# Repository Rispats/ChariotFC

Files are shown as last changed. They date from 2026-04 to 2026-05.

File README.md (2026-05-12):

# ChariotFC

> Custom Flight Controller + PDB for General Free Style and Auotpilot applications

## Specs
- **FMU:** AT32F435RMT7 (288Mhz, Hardware FPU)
- **Power Distrubution Board:** 2S-6S LiPo 
- **From Factor:** 30.5mm X 30.5mm Dual stack (FC + PDB)
- **Target Firmware:** PX4, Betaflight

STATUS: PCB Design in progress

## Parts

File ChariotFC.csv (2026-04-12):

Reference | Qty | Value | DNP | Exclude from BOM | Exclude from Board | Footprint | Datasheet
BUZZER1 | 1 | MLT-7525 |  |  | Excluded from board | easyeda2kicad:BUZ-SMD_4P-L7.5-W7.5-P7.59-TL | https://lcsc.com/product-detail/Buzzers_MLT-7525_C95299.html
C1,C8 | 2 | 1uF |  |  |  | easyeda2kicad:C0402 | https://lcsc.com/product-detail/Multilayer-Ceramic-Capacitors-MLCC-SMD-SMT_SAMSUNG_CL05A105KA5NQNC_1uF-105-10-25V_C52923.html,https://lcsc.com/product-detail/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
C2,C3,C4,C9,C11,C12,C13,C14,C40 | 9 | 100nF |  |  |  | easyeda2kicad:C0402 | https://lcsc.com/product-detail/Multilayer-Ceramic-Capacitors-MLCC-SMD-SMT_SAMSUNG_CL05A104KA5NNNC_100nF-104-10-25V_C100072.html,https://lcsc.com/product-deta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
C5,C20,C35 | 3 | 100nF |  |  |  | PCM_JLCPCB:C_0402 | https://www.lcsc.com/datasheet/lcsc_datasheet_2304140030_Samsung-Electro-Mechanics-CL05B104KB54PNC_C307331.pdf,https://www.lcsc.com/datasheet/lcsc_datasheet_2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
C6,C7 | 2 | 33pF |  |  |  | easyeda2kicad:C0402 | https://lcsc.com/product-detail/Multilayer-Ceramic-Capacitors-MLCC-SMD-SMT_33pF-330-5-50V_C1562.html
C10 | 1 | 10nF |  |  |  | easyeda2kicad:C0402 | https://lcsc.com/product-detail/Multilayer-Ceramic-Capacitors-MLCC-SMD-SMT_muRata_GRM155R71H103KA88D_10nF-103-10-50V_C77019.html
C15 | 1 | 4.7uF |  |  |  | easyeda2kicad:C0805 | https://lcsc.com/product-detail/Multilayer-Ceramic-Capacitors-MLCC-SMD-SMT_SAMSUNG_CL21A475KAQNNNE_4-7uF-475-10-25V_C1779.html
C16,C17,C18,C19 | 4 | 1uF |  |  |  | PCM_JLCPCB:C_0402 | https://www.lcsc.com/datasheet/lcsc_datasheet_2304140030_Samsung-Electro-Mechanics-CL05A105KA5NQNC_C52923.pdf
C21 | 1 | 10uF |  |  |  | easyeda2kicad:C1206
C22,C23,C25,C26,C27,C29,C30,C31 | 8 | 100nF |  |  | Excluded from board | PCM_JLCPCB:C_0402 | https://www.lcsc.com/datasheet/lcsc_datasheet_2304140030_Samsung-Electro-Mechanics-CL05B104KO5NNNC_C1525.pdf
C24 | 1 | 10uF |  |  | Excluded from board | PCM_JLCPCB:C_0603 | https://www.lcsc.com/datasheet/lcsc_datasheet_2304140030_Samsung-Electro-Mechanics-CL10A106KP8NNNC_C19702.pdf
C28 | 1 | 1uF |  |  | Excluded from board | PCM_JLCPCB:C_0402 | https://www.lcsc.com/datasheet/lcsc_datasheet_2304140030_Samsung-Electro-Mechanics-CL05A105KA5NQNC_C52923.pdf
C32,C33 | 2 | 10uF |  |  |  | PCM_JLCPCB:C_0805 | https://www.lcsc.com/datasheet/lcsc_datasheet_2411041759_Murata-Electronics-GRM21BR61H106KE43L_C440198.pdf
C34 | 1 | 10nF |  |  |  | PCM_JLCPCB:C_0402 | https://www.lcsc.com/datasheet/lcsc_datasheet_2304140030_Samsung-Electro-Mechanics-CL05B103KB5NNNC_C15195.pdf
C36 | 1 | 33nF |  |  |  | PCM_JLCPCB:C_0603 | https://www.lcsc.com/datasheet/lcsc_datasheet_2304140030_Samsung-Electro-Mechanics-CL10B333KB8NNNC_C21117.pdf
C37 | 1 | 100nF 25v |  |  |  | easyeda2kicad:C0402 | https://lcsc.com/product-detail/Multilayer-Ceramic-Capacitors-MLCC-SMD-SMT_SAMSUNG_CL05A104KA5NNNC_100nF-104-10-25V_C100072.html
C38,C39 | 2 | 22uF |  |  |  | easyeda2kicad:C1206 | https://lcsc.com/product-detail/Multilayer-Ceramic-Capacitors-MLCC-SMD-SMT_muRata_GRM31CR71A226KE15L_22uF-226-10-10V_C91604.html
D1,D2 | 2 | PMEG4020ER,115 |  |  |  | easyeda2kicad:SOD-123_L2.8-W1.8-LS3.7-RD | https://lcsc.com/product-detail/Others_Nexperia_PMEG4020ER-115_Nexperia-PMEG4020ER-115_C255588.html
D3 | 1 | 1N4148W_C81598 |  |  | Excluded from board | easyeda2kicad:SOD-123F_L2.7-W1.6-LS3.8-RD | https://lcsc.com/product-detail/Switching-Diode_1N4148W_C81598.html
D4 | 1 | MM3Z3V3T1G |  |  |  | easyeda2kicad:SOD-323_L1.8-W1.3-LS2.5-RD | https://lcsc.com/product-detail/Zener-Diodes_ON_MM3Z3V3T1G_MM3Z3V3T1G_C75073.html
L1 | 1 | BLM15AG601SN1D |  |  |  | easyeda2kicad:L0402 | https://lcsc.com/product-detail/Ferrite-Beads-And-Chips_muRata_BLM15AG601SN1D_600R-at100MHz_C76884.html
L2 | 1 | 6.8uH |  |  |  | easyeda2kicad:IND-SMD_L7.1-W6.6
LED1 | 1 | 3v3_PWR |  |  |  | easyeda2kicad:LED0805-R-RD | https://lcsc.com/product-detail/Light-Emitting-Diodes-LED_Green-0805-Highlighted_C2297.html
LED2 | 1 | 3v3_SENSORS_PWR |  |  |  | easyeda2kicad:LED0805-R-RD | https://lcsc.com/product-detail/Light-Emitting-Diodes-LED_Green-0805-Highlighted_C2297.html
LED3 | 1 | KT-0603R |  |  | Excluded from board | easyeda2kicad:LED0603-RD | https://lcsc.com/product-detail/Light-Emitting-Diodes-LED_Red-LED-0603_C2286.html
LED4 | 1 | XL-0603QYGC |  |  | Excluded from board | easyeda2kicad:LED0603-RD | https://lcsc.com/product-detail/Light-Emitting-Diodes-LED_Yellow-green-0603_C2289.html
LED5 | 1 | SYS_PWR_ON |  |  |  | easyeda2kicad:LED0603-RD | https://lcsc.com/product-detail/Light-Emitting-Diodes-LED_Red-LED-0603_C2286.html
Q1 | 1 | 2N7002 |  |  | Excluded from board | easyeda2kicad:SOT-23-3_L2.9-W1.3-P1.90-LS2.4-BR | https://lcsc.com/product-detail/MOSFET_2N7002-7002_C8545.html
R1,R3,R4,R5 | 4 | 10k |  |  |  | easyeda2kicad:R0402 | https://lcsc.com/product-detail/Chip-Resistor-Surface-Mount_10KR-1002-1_C60490.html
R2 | 1 | 10kΩ |  |  |  | PCM_JLCPCB:R_0402x4 | https://www.lcsc.com/datasheet/lcsc_datasheet_2409272301_UNI-ROYAL-Uniroyal-Elec-4D02WGJ0103TCE_C25725.pdf
R6,R7 | 2 | 5.1kΩ |  |  |  | PCM_JLCPCB:R_0402 | https://www.lcsc.com/datasheet/lcsc_datasheet_2206010045_UNI-ROYAL-Uniroyal-Elec-0402WGF5101TCE_C25905.pdf
R8,R9 | 2 | 100 |  |  |  | easyeda2kicad:R0402 | https://lcsc.com/product-detail/Chip-Resistor-Surface-Mount-UniOhm_100R-1000-1_C25076.html
R10,R11 | 2 | 22Ω |  |  |  | PCM_JLCPCB:R_0402 | https://www.lcsc.com/datasheet/lcsc_datasheet_2205311900_UNI-ROYAL-Uniroyal-Elec-0402WGF220JTCE_C25092.pdf
R12 | 1 | 100 |  |  | Excluded from board | easyeda2kicad:R0402 | https://lcsc.com/product-detail/Chip-Resistor-Surface-Mount-UniOhm_100R-1000-1_C25076.html
R13,R19 | 2 | 10kΩ |  |  | Excluded from board | PCM_JLCPCB:R_0402 | https://www.lcsc.com/datasheet/lcsc_datasheet_2411221126_UNI-ROYAL-Uniroyal-Elec-0402WGF1002TCE_C25744.pdf
R14 | 1 | 100kΩ |  |  | Excluded from board | PCM_JLCPCB:R_0402 | https://www.lcsc.com/datasheet/lcsc_datasheet_2206010100_UNI-ROYAL-Uniroyal-Elec-0402WGF1003TCE_C25741.pdf
R15,R16,R17,R18 | 4 | 33Ω |  |  | Excluded from board | PCM_JLCPCB:R_0402 | https://www.lcsc.com/datasheet/lcsc_datasheet_2205311900_UNI-ROYAL-Uniroyal-Elec-0402WGF330JTCE_C25105.pdf
R20 | 1 | 2m |  |  |  | easyeda2kicad:RES-SMD_L6.4-W3.2-1
R21 | 1 | 100Ω |  |  |  | PCM_JLCPCB:R_0402 | https://www.lcsc.com/datasheet/lcsc_datasheet_2205311900_UNI-ROYAL-Uniroyal-Elec-0402WGF1000TCE_C25076.pdf
R22 | 1 | 75kΩ |  |  |  | PCM_JLCPCB:R_0402 | https://www.lcsc.com/datasheet/lcsc_datasheet_2206010045_UNI-ROYAL-Uniroyal-Elec-0402WGF7502TCE_C25798.pdf
R23 | 1 | 10kΩ |  |  |  | PCM_JLCPCB:R_0402 | https://www.lcsc.com/datasheet/lcsc_datasheet_2411221126_UNI-ROYAL-Uniroyal-Elec-0402WGF1002TCE_C25744.pdf
R24 | 1 | 10.2k |  |  |  | easyeda2kicad:R0805
R25 | 1 | 220Ω |  |  |  | PCM_JLCPCB:R_0603 | https://www.lcsc.com/datasheet/lcsc_datasheet_2206010130_UNI-ROYAL-Uniroyal-Elec-0603WAF2200T5E_C22962.pdf
SIM1 | 1 | SD CARD |  |  |  | easyeda2kicad:SIM-SMD_8P-1040310811
SW1,SW2 | 2 | 1TS009A-1800-5000 |  |  |  | easyeda2kicad:KEY-SMD_L6.0-W6.0-LS6.6 | https://lcsc.com/product-detail/Others_HYP-1TS009A-1800-5000_C319409.html
TP1,TP2,TP3,TP4,TP5,TP6,TP7,TP8,TP9,TP10,TP11,TP12,TP13,TP14,TP15,TP16,TP17,TP18 | 18 | TestPoint |  |  | Excluded from board |  | ~
TP19,TP21,TP23,TP25,TP27 | 5 | BATT+ |  |  |  |  | ~
TP20,TP22,TP24,TP26,TP28 | 5 | BATT- |  |  |  |  | ~
TP29 | 1 | 5V_test |  |  |  |  | ~
TP30 | 1 | GND |  |  |  |  | ~
U1 | 1 | AT32F435RMT7 |  |  |  | easyeda2kicad:LQFP-64_L10.0-W10.0-P0.50-LS12.0-BL
U2 | 1 | FM25V20A-DGTR_C2952834 |  |  |  | easyeda2kicad:DFN-8_L6.0-W5.0-P1.27-BL-EP
U3 | 1 | NCP167BMX330TBG |  |  |  | easyeda2kicad:XDFN-4_L1.0-W1.0-P0.65-BL-EP
U4 | 1 | TLV75733PDRVR |  |  |  | easyeda2kicad:TDFN-6_L2.0-W2.0-P0.65-TL-EP
U5,U14 | 2 | B6B-XH-A(LF)(SN) |  |  |  | easyeda2kicad:CONN-TH_6P-P2.50_B6B-XH-A-LF-SN | https://lcsc.com/product-detail/XH-Connectors_JST-Sales-America_B6B-XH-A-LF-SN_JST-Sales-America-B6B-XH-A-LF-SN_C144397.html
U6 | 1 | USBLC6-2SC6Y_C2969755 |  |  |  | easyeda2kicad:SOT-23-6_L2.9-W1.7-P0.95-LS2.8-BL
U7 | 1 | MMC5983MA |  |  | Excluded from board | easyeda2kicad:LGA-16_L3.0-W3.0-P0.50-BL_SQ | https://lcsc.com/product-detail/Magnetic-Sensors_MEMSIC-MMC5983MA_C404329.html
U8 | 1 | ICM-45686 |  |  | Excluded from board | easyeda2kicad:LGA-14_L3.0-W2.5-P0.50-TL
U9 | 1 | ICP-20100 |  |  | Excluded from board | easyeda2kicad:LGA-10_L2.0-W2.0-P0.50-TL_ICP-20100
U10 | 1 | SAM-M10Q-00B |  |  | Excluded from board | easyeda2kicad:LCC-20_L15.5-W15.5-P1.90_SAM-M10Q-00B
U11 | 1 | INA240A1QDRQ1 |  |  |  | easyeda2kicad:SOIC-8_L4.9-W3.9-P1.27-LS6.0-BL-2
U12 | 1 | TPS62933DRLR |  |  |  | easyeda2kicad:SOT-583-8_L2.1-W1.2-P0.50-LS1.6-BR
U13 | 1 | 53.6k |  |  |  | easyeda2kicad:R0603
USBC1 | 1 | TYPE-C-31-M-12 |  |  |  | easyeda2kicad:USB-C_SMD-TYPE-C-31-M-12_1 | https://lcsc.com/product-detail/USB-Type-C_Korean-Hroparts-Elec-TYPE-C-31-M-12_C165948.html
X1 | 1 | ABM3-8.000MHZ-D2Y-T |  |  |  | easyeda2kicad:OSC-SMD_L5.0-W3.2 | https://lcsc.com/product-detail/SMD-Crystals_ABRACON_ABM3-8-000MHZ-D2Y-T_8MHZ-20ppm-400C-850C_C144380.html

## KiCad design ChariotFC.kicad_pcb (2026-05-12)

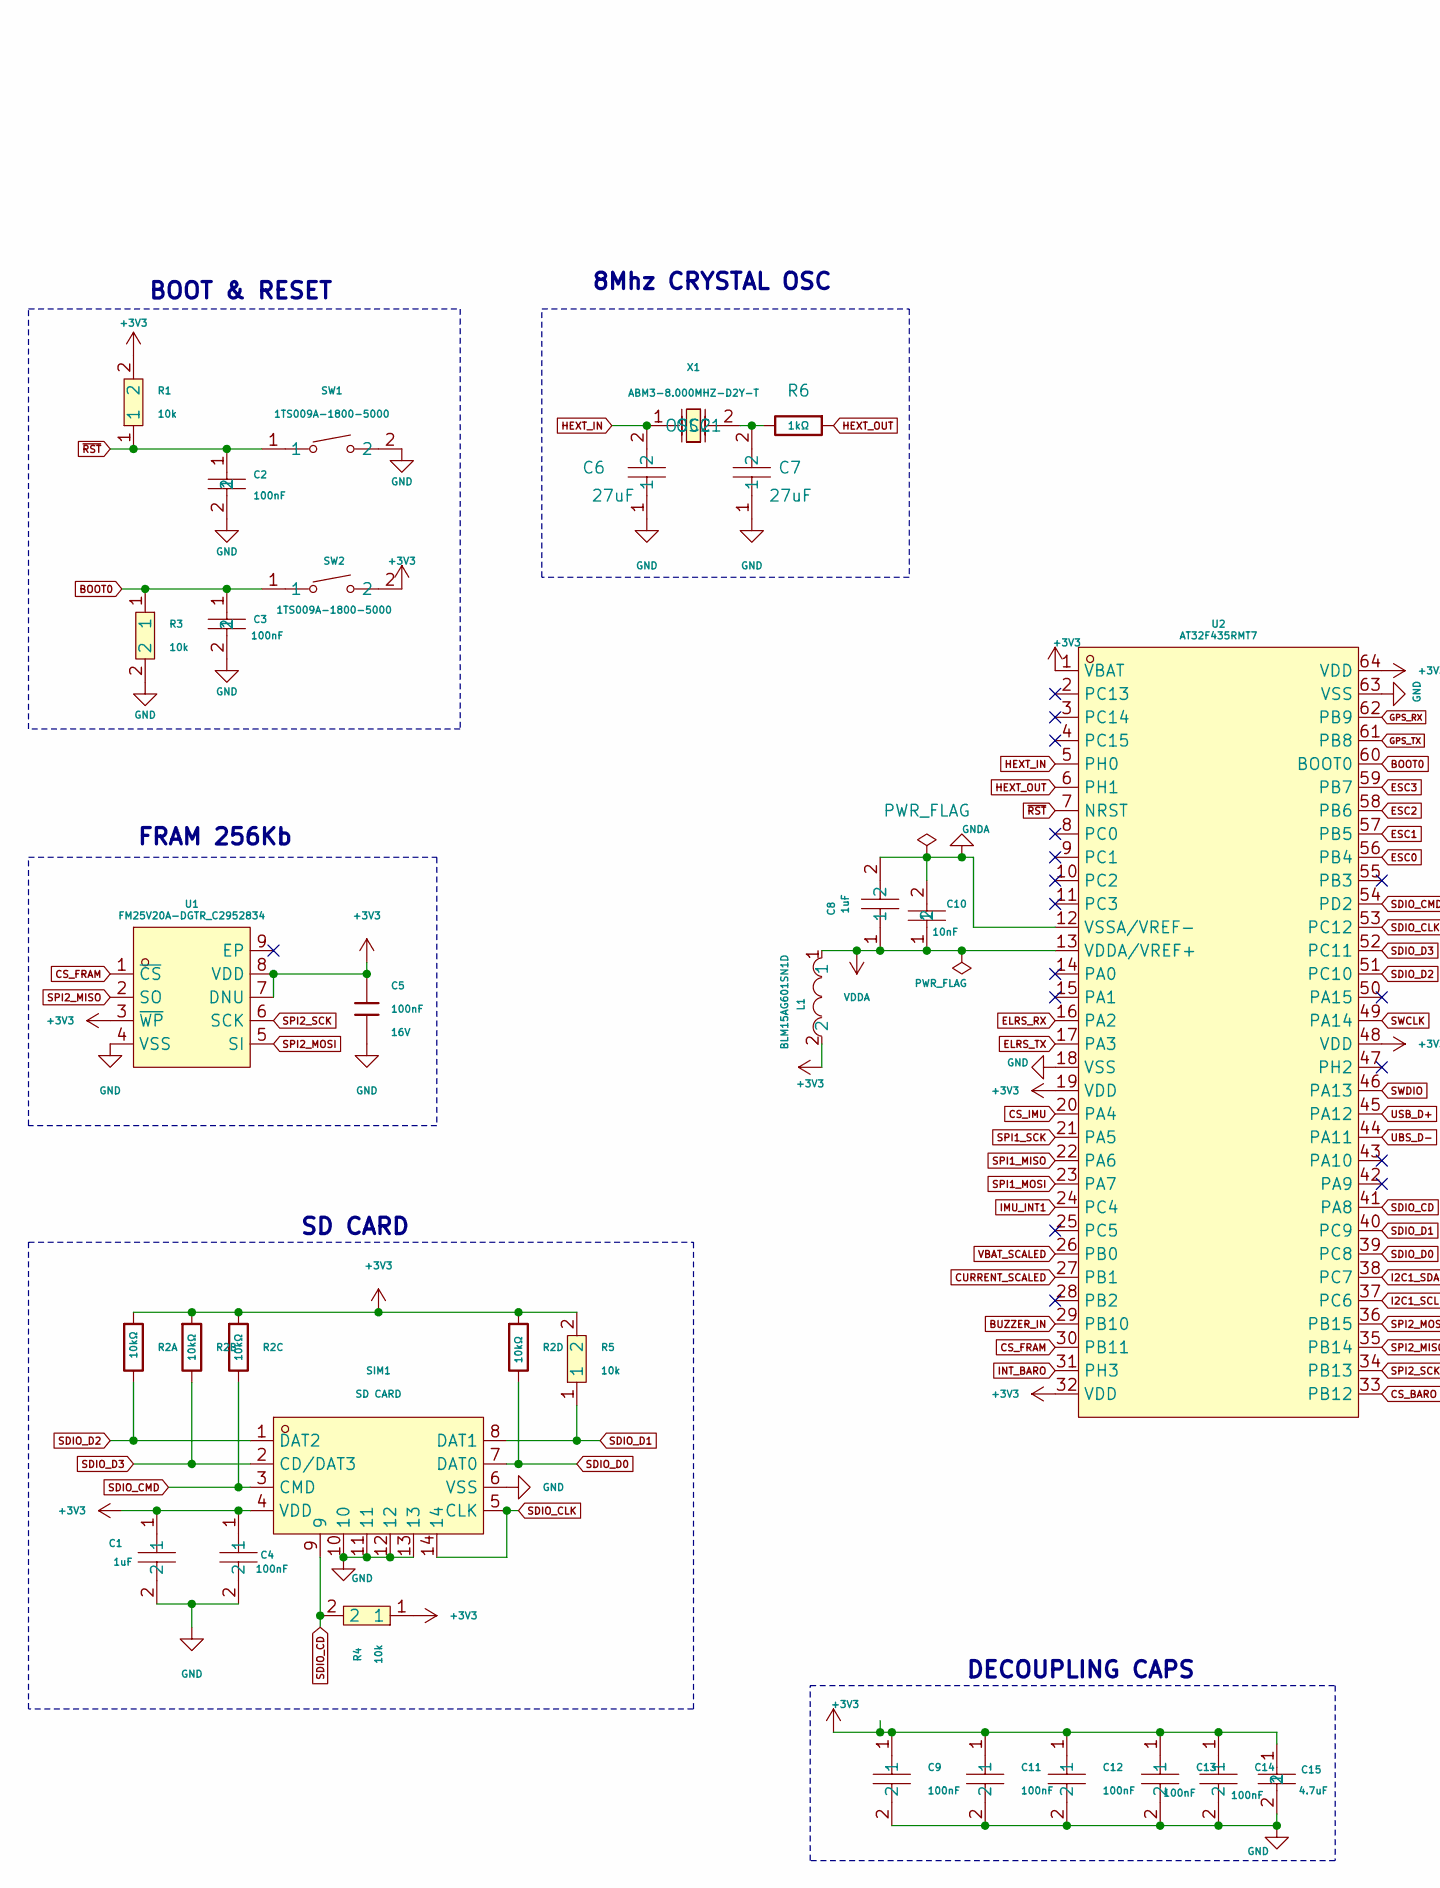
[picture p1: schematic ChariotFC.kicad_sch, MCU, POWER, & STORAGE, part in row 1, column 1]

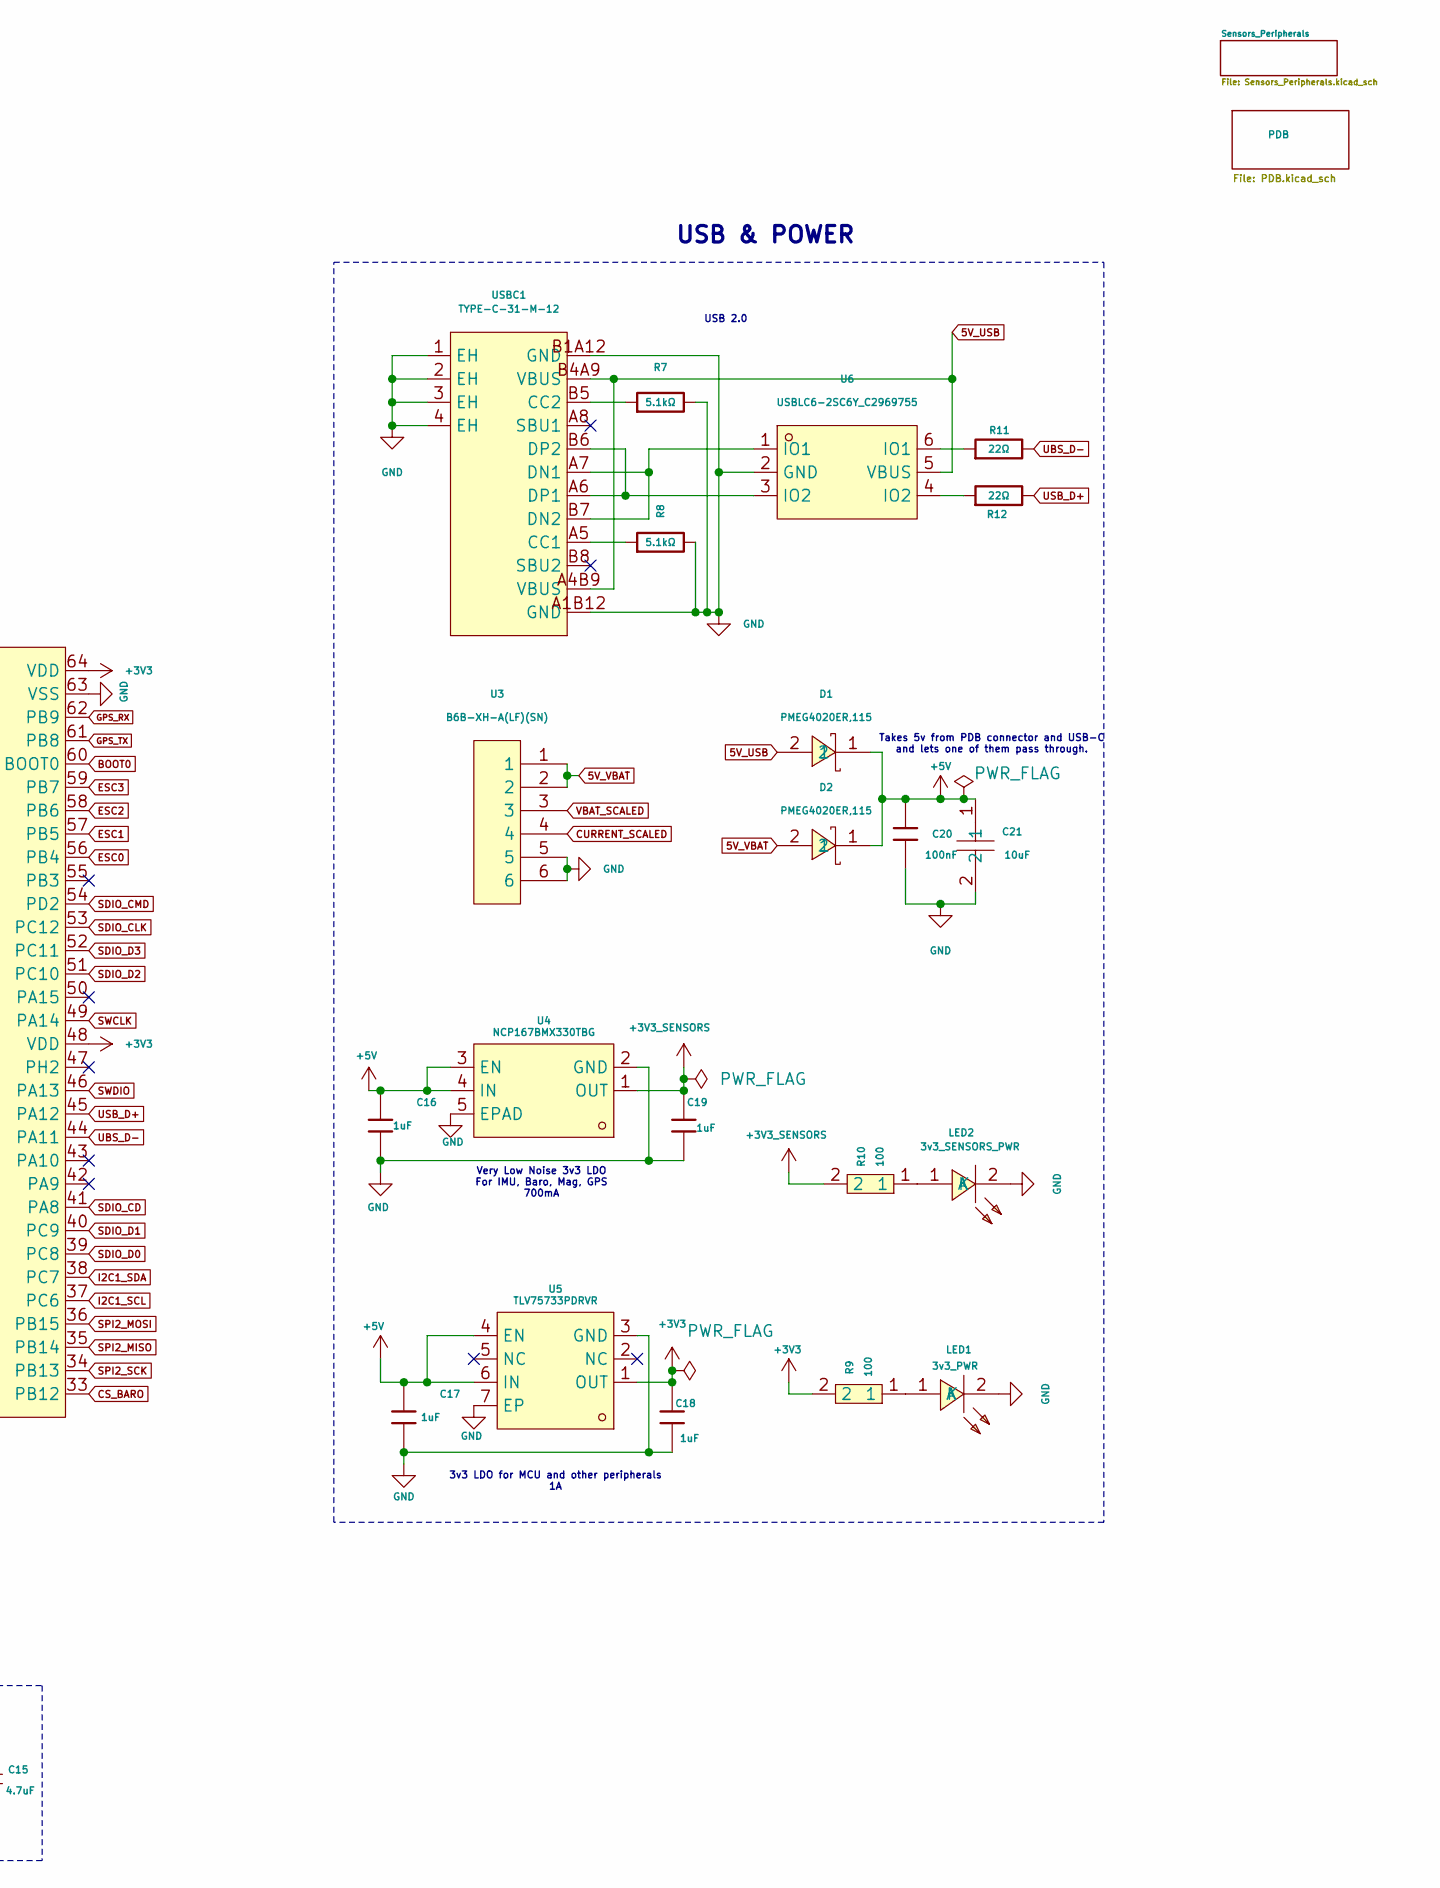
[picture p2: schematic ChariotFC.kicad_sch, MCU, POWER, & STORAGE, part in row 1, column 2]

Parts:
C1: 1uF; C0402; LCSC Part C52923
C2, C3: 100nF; C0402; LCSC Part C77019
C4, C9, C11, C12, C13, C14: 100nF; C0402; LCSC Part C1525
C5, C20: 100nF; C0402; Voltage Rated 16V; Tolerance ±10%; Part CL05B104KO5NNNC; LCSC C1525
C6, C7: 27uF; C0402; LCSC Part C445761
C8: 1uF; C0402; LCSC Part C15684
C10: 10nF; C0402; LCSC Part C77019
C15: 4.7uF; C0805; LCSC Part C1779
C16, C17, C18, C19: 1uF; C0402; Voltage Rated 25V; Tolerance ±10%; Part CL05A105KA5NQNC; LCSC C52923
C21: 10uF; C1206; LCSC Part C6119987
D1, D2: PMEG4020ER,115; SOD-123_L2.8-W1.8-LS3.7-RD; LCSC Part C255588
L1: BLM15AG601SN1D; L0402; LCSC Part C76884
LED1: 3v3_PWR; LED0805-R-RD; LCSC Part C2297
LED2: 3v3_SENSORS_PWR; LED0805-R-RD; LCSC Part C2297
R1, R3, R4, R5: 10k; R0402; LCSC Part C60490
R2: 10kΩ; RES-ARRAY-SMD_0402-8P-L2.0-W1.0-BL; Tolerance ±5%; Part 4D02WGJ0103TCE; LCSC C25725
R6: 1kΩ; R0402; Overload Voltage (Max) 50V; Tolerance ±1%; Part 0402WGF1001TCE; LCSC C11702
R7, R8: 5.1kΩ; R0402; Overload Voltage (Max) 50V; Tolerance ±1%; Part 0402WGF5101TCE; LCSC C25905
R9, R10: 100; R0402; LCSC Part C25076
R11, R12: 22Ω; R0402; Overload Voltage (Max) 50V; Tolerance ±1%; Part 0402WGF220JTCE; LCSC C25092
SIM1: SD CARD; SIM-SMD_8P-1040310811; LCSC Part C585350
SW1, SW2: 1TS009A-1800-5000; KEY-SMD_L6.0-W6.0-LS6.6; LCSC Part C319409
U1: FM25V20A-DGTR_C2952834; DFN-8_L6.0-W5.0-P1.27-BL-EP; LCSC Part C2952834
U2: AT32F435RMT7; LQFP-64_L10.0-W10.0-P0.50-LS12.0-BL; LCSC Part C5178940
U3: B6B-XH-A(LF)(SN); CONN-TH_6P-P2.50_B6B-XH-A-LF-SN; LCSC Part C144397
U4: NCP167BMX330TBG; XDFN-4_L1.0-W1.0-P0.65-BL-EP; LCSC Part C892227
U5: TLV75733PDRVR; TDFN-6_L2.0-W2.0-P0.65-TL-EP; LCSC Part C2868428
U6: USBLC6-2SC6Y_C2969755; SOT-23-6_L2.9-W1.7-P0.95-LS2.8-BL; LCSC Part C2969755
USBC1: TYPE-C-31-M-12; USB-C_SMD-TYPE-C-31-M-12_1; LCSC Part C165948
X1: ABM3-8.000MHZ-D2Y-T; OSC-SMD_L5.0-W3.2; LCSC Part C144380

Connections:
5V_USB: D1.2, U6.5 (VBUS), USBC1.A4B9 (VBUS), USBC1.B4A9 (VBUS)
5V_VBAT: D2.2, U3.1, U3.2; also elsewhere on the board
+3V3: C1.1, C4.1, C5.1, C9.1, C11.1, C12.1, C13.1, C14.1, C15.1, C18.1, L1.2, R1.2, R2.1, R2.2, R2.3, R2.4, R4.1, R5.2, R9.2, SIM1.4 (VDD), SW2.2, U1.3 (~WP), U1.7 (DNU), U1.8 (VDD), U2.1 (VBAT), U2.19 (VDD), U2.32 (VDD), U2.48 (VDD), U2.64 (VDD), U5.1 (OUT); also elsewhere on the board
+3V3_SENSORS: C19.1, R10.2, U4.1 (OUT); also elsewhere on the board
+5V: C16.1, C17.1, C20.2, C21.1, D1.1, D2.1, U4.3 (EN), U4.4 (IN), U5.4 (EN), U5.6 (IN); also elsewhere on the board
BOOT0: C3.1, R3.1, SW2.1, U2.60 (BOOT0)
BUZZER_IN: U2.29 (PB10); also elsewhere on the board
CS_BARO: U2.33 (PB12); also elsewhere on the board
CS_FRAM: U1.1 (~CS), U2.30 (PB11)
CS_IMU: U2.20 (PA4); also elsewhere on the board
CURRENT_SCALED: U2.27 (PB1), U3.4; also elsewhere on the board
ELRS_RX: U2.16 (PA2); also elsewhere on the board
ELRS_TX: U2.17 (PA3); also elsewhere on the board
ESC0: U2.56 (PB4); also elsewhere on the board
ESC1: U2.57 (PB5); also elsewhere on the board
ESC2: U2.58 (PB6); also elsewhere on the board
ESC3: U2.59 (PB7); also elsewhere on the board
GND: C1.2, C2.2, C3.2, C4.2, C5.2, C6.1, C7.1, C9.2, C11.2, C12.2, C13.2, C14.2, C15.2, C16.2, C17.2, C18.2, C19.2, C20.1, C21.2, LED1.2 (K), LED2.2 (K), R3.2, R7.2, R8.2, SIM1.6 (VSS), SIM1.10, SIM1.11, SIM1.12, SIM1.13, SW1.2, U1.4 (VSS), U2.18 (VSS), U2.63 (VSS), U3.5, U3.6, U4.2 (GND), U4.5 (EPAD), U5.3 (GND), U5.7 (EP), U6.2 (GND), USBC1.1 (EH), USBC1.2 (EH), USBC1.3 (EH), USBC1.4 (EH), USBC1.A1B12 (GND), USBC1.B1A12 (GND); also elsewhere on the board
GNDA: C8.2, C10.2, U2.12 (VSSA/VREF-)
GPS_RX: U2.62 (PB9); also elsewhere on the board
GPS_TX: U2.61 (PB8); also elsewhere on the board
HEXT_IN: C6.2, U2.5 (PH0), X1.1 (OSC1); also elsewhere on the board
HEXT_OUT: R6.1, U2.6 (PH1)
I2C1_SCL: U2.37 (PC6); also elsewhere on the board
I2C1_SDA: U2.38 (PC7); also elsewhere on the board
IMU_INT1: U2.24 (PC4); also elsewhere on the board
INT_BARO: U2.31 (PH3); also elsewhere on the board
unnamed: LED1.1 (A), R9.1
unnamed: LED2.1 (A), R10.1
unnamed: R11.1, U6.6 (IO1)
unnamed: R12.1, U6.4 (IO2)
unnamed: R8.1, USBC1.A5 (CC1)
unnamed: R7.1, USBC1.B5 (CC2)
unnamed: U6.1 (IO1), USBC1.A7 (DN1), USBC1.B7 (DN2)
unnamed: U6.3 (IO2), USBC1.A6 (DP1), USBC1.B6 (DP2)
unnamed 56: C7.2, R6.2, X1.2 (OSC2); also elsewhere on the board
SDIO_CD: R4.2, SIM1.9, U2.41 (PA8)
SDIO_CLK: SIM1.5 (CLK), SIM1.14, U2.53 (PC12)
SDIO_CMD: R2.6, SIM1.3 (CMD), U2.54 (PD2)
SDIO_D0: R2.5, SIM1.7 (DAT0), U2.39 (PC8)
SDIO_D1: R5.1, SIM1.8 (DAT1), U2.40 (PC9)
SDIO_D2: R2.8, SIM1.1 (DAT2), U2.51 (PC10)
SDIO_D3: R2.7, SIM1.2 (CD/DAT3), U2.52 (PC11)
SPI1_MISO: U2.22 (PA6); also elsewhere on the board
SPI1_MOSI: U2.23 (PA7); also elsewhere on the board
SPI1_SCK: U2.21 (PA5); also elsewhere on the board
SPI2_MISO: U1.2 (SO), U2.35 (PB14); also elsewhere on the board
SPI2_MOSI: U1.5 (SI), U2.36 (PB15); also elsewhere on the board
SPI2_SCK: U1.6 (SCK), U2.34 (PB13); also elsewhere on the board
SWCLK: U2.49 (PA14); also elsewhere on the board
SWDIO: U2.46 (PA13); also elsewhere on the board
UBS_D-: R11.2, U2.44 (PA11)
USB_D+: R12.2, U2.45 (PA12)
VBAT_SCALED: U2.26 (PB0), U3.3; also elsewhere on the board
VDDA: C8.1, C10.1, L1.1, U2.13 (VDDA/VREF+)
~RST: C2.1, R1.1, SW1.1, U2.7 (NRST)

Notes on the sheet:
3v3 LDO for MCU and other peripherals 1A
USB & POWER
USB 2.0
Takes 5v from PDB connector and USB-C and lets one of them pass through.
SD CARD
DECOUPLING CAPS
BOOT & RESET
FRAM 256Kb
8Mhz CRYSTAL OSC
Very Low Noise 3v3 LDO For IMU, Baro, Mag, GPS 700mA

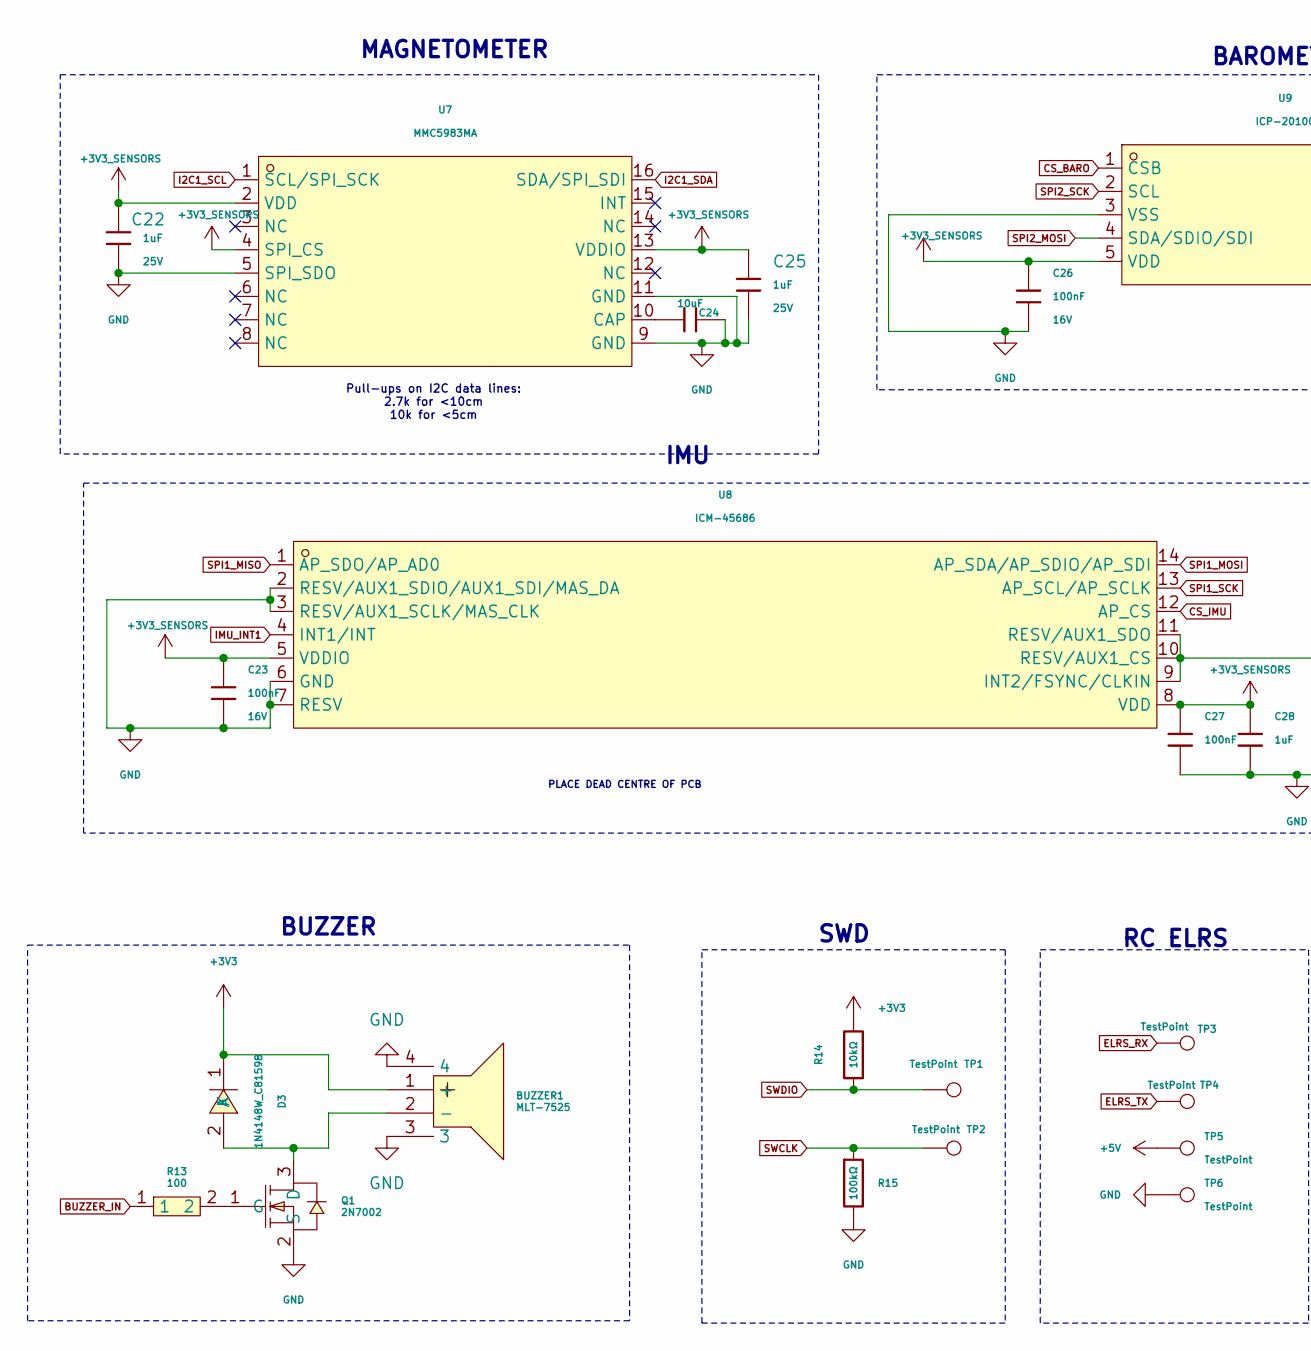
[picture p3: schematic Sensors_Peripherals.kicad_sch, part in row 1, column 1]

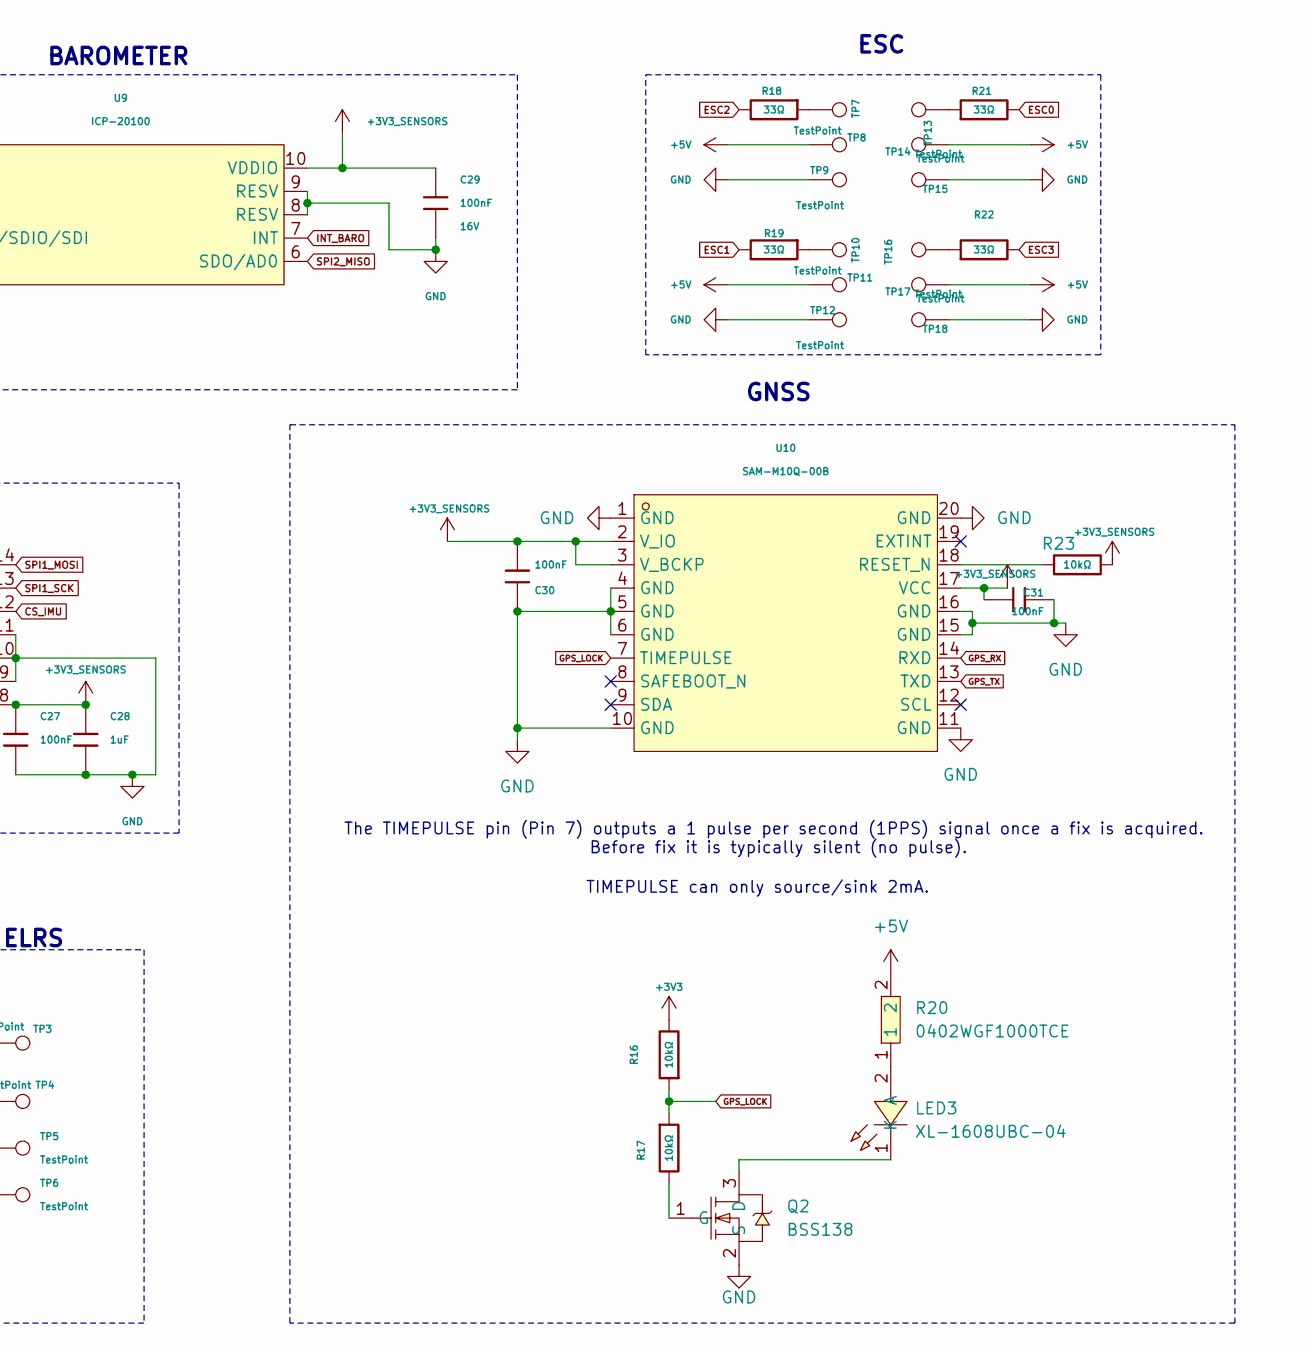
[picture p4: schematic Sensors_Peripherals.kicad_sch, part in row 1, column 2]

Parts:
BUZZER1: MLT-7525; BUZ-SMD_4P-L7.5-W7.5-P7.59-TL; LCSC Part C95299
C22, C25, C28: 1uF; C0402; Voltage Rated 25V; Tolerance ±10%; Part CL05A105KA5NQNC; LCSC C52923
C23, C26, C27, C29, C30, C31: 100nF; C0402; Voltage Rated 16V; Tolerance ±10%; Part CL05B104KO5NNNC; LCSC C1525
C24: 10uF; C0603; Voltage Rated 10V; Tolerance ±10%; Part CL10A106KP8NNNC; LCSC C19702
D3: 1N4148W_C81598; SOD-123F_L2.7-W1.6-LS3.8-RD; LCSC Part C81598
LED3: XL-1608UBC-04; LED0603-RD_BLUE; MPN XL-1608UBC-04; LCSC Part C965807
Q1: 2N7002; SOT-23-3_L2.9-W1.3-P1.90-LS2.4-BR; LCSC Part C8545
Q2: BSS138; SOT-23-3_L2.9-W1.6-P1.90-LS2.8-BR; MPN BSS138; LCSC Part C52895
R13: 100; R0402; LCSC Part C25076
R14, R16, R17: 10kΩ; R0402; Overload Voltage (Max) 50V; Tolerance ±1%; Part 0402WGF1002TCE; LCSC C25744
R15: 100kΩ; R0402; Overload Voltage (Max) 50V; Tolerance ±1%; Part 0402WGF1003TCE; LCSC C25741
R18, R19: 33Ω; R0402; Overload Voltage (Max) 50V; Tolerance ±1%; Part 0402WGF330JTCE; LCSC C25105
R20: 0402WGF1000TCE; R0402; MPN 0402WGF1000TCE; LCSC Part C25076
R21, R22: 33Ω; C0402; Overload Voltage (Max) 50V; Tolerance ±1%; Part 0402WGF330JTCE; LCSC C25105
R23: 10kΩ; C0402; Overload Voltage (Max) 50V; Tolerance ±1%; Part 0402WGF1002TCE; LCSC C25744
TP1, TP2: TestPoint; TestPoint_THTPad_D2.0mm_Drill1.0mm
TP3, TP4, TP5, TP6, TP7, TP8, TP9, TP10, TP11, TP12, TP13, TP14, TP15, TP16, TP17, TP18: TestPoint; TestPoint_Pad_4.0x4.0mm
U7: MMC5983MA; LGA-16_L3.0-W3.0-P0.50-BL_SQ; LCSC Part C404329
U8: ICM-45686; LGA-14_L3.0-W2.5-P0.50-TL; LCSC Part C22459454
U9: ICP-20100; LGA-10_L2.0-W2.0-P0.50-TL_ICP-20100; LCSC Part C5343527
U10: SAM-M10Q-00B; LCC-20_L15.5-W15.5-P1.90_SAM-M10Q-00B; LCSC Part C5443880

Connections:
+3V3: BUZZER1.1 (+), D3.1 (K), R14.2, R16.2; also elsewhere on the board
+3V3_SENSORS: C22.1, C23.1, C25.1, C26.2, C27.1, C28.1, C29.1, C30.1, C31.1, R23.2, U7.2 (VDD), U7.4 (SPI_CS), U7.13 (VDDIO), U8.5 (VDDIO), U8.8 (VDD), U9.5 (VDD), U9.10 (VDDIO), U10.2 (V_IO), U10.3 (V_BCKP), U10.17 (VCC); also elsewhere on the board
+5V: R20.2, TP5.1 (1_1), TP8.1 (1_1), TP11.1 (1_1), TP14.1 (1_1), TP17.1 (1_1); also elsewhere on the board
BUZZER_IN: R13.1; also elsewhere on the board
CS_BARO: U9.1 (CSB); also elsewhere on the board
CS_IMU: U8.12 (AP_CS); also elsewhere on the board
ELRS_RX: TP3.1 (1_1); also elsewhere on the board
ELRS_TX: TP4.1 (1_1); also elsewhere on the board
ESC0: R21.2; also elsewhere on the board
ESC1: R19.2; also elsewhere on the board
ESC2: R18.2; also elsewhere on the board
ESC3: R22.2; also elsewhere on the board
GND: BUZZER1.3, BUZZER1.4, C22.2, C23.2, C24.2, C25.2, C26.1, C27.2, C28.2, C29.2, C30.2, C31.2, Q1.2 (S), Q2.2 (S), R15.2, TP6.1 (1_1), TP9.1 (1_1), TP12.1 (1_1), TP15.1 (1_1), TP18.1 (1_1), U7.5 (SPI_SDO), U7.9 (GND), U7.11 (GND), U8.2 (RESV/AUX1_SDIO/AUX1_SDI/MAS_DA), U8.3 (RESV/AUX1_SCLK/MAS_CLK), U8.6 (GND), U8.7 (RESV), U8.9 (INT2/FSYNC/CLKIN), U8.10 (RESV/AUX1_CS), U8.11 (RESV/AUX1_SDO), U9.3 (VSS), U9.8 (RESV), U9.9 (RESV), U10.1 (GND), U10.4 (GND), U10.5 (GND), U10.6 (GND), U10.10 (GND), U10.11 (GND), U10.15 (GND), U10.16 (GND), U10.20 (GND); also elsewhere on the board
GPS_LOCK: R16.1, R17.1, U10.7 (TIMEPULSE)
GPS_RX: U10.14 (RXD); also elsewhere on the board
GPS_TX: U10.13 (TXD); also elsewhere on the board
I2C1_SCL: U7.1 (SCL/SPI_SCK); also elsewhere on the board
I2C1_SDA: U7.16 (SDA/SPI_SDI); also elsewhere on the board
IMU_INT1: U8.4 (INT1/INT); also elsewhere on the board
INT_BARO: U9.7 (INT); also elsewhere on the board
unnamed: BUZZER1.2 (-), D3.2 (A), Q1.3 (D)
unnamed: LED3.2 (A), R20.1
unnamed: LED3.1 (K), Q2.3 (D)
unnamed: Q1.1 (G), R13.2
unnamed: Q2.1 (G), R17.2
unnamed: R18.1, TP7.1 (1_1)
unnamed: R19.1, TP10.1 (1_1)
unnamed: R21.1, TP13.1 (1_1)
unnamed: R22.1, TP16.1 (1_1)
unnamed: C24.1, U7.10 (CAP)
unnamed: R23.1, U10.18 (RESET_N)
SPI1_MISO: U8.1 (AP_SDO/AP_AD0); also elsewhere on the board
SPI1_MOSI: U8.14 (AP_SDA/AP_SDIO/AP_SDI); also elsewhere on the board
SPI1_SCK: U8.13 (AP_SCL/AP_SCLK); also elsewhere on the board
SPI2_MISO: U9.6 (SDO/AD0); also elsewhere on the board
SPI2_MOSI: U9.4 (SDA/SDIO/SDI); also elsewhere on the board
SPI2_SCK: U9.2 (SCL); also elsewhere on the board
SWCLK: R15.1, TP2.1 (1_1); also elsewhere on the board
SWDIO: R14.1, TP1.1 (1_1); also elsewhere on the board

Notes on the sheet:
BAROMETER
ESC
SWD
The TIMEPULSE pin (Pin 7) outputs a 1 pulse per second (1PPS) signal once a fix is acquired. Before fix it is typically silent (no pulse).
IMU
PLACE DEAD CENTRE OF PCB
TIMEPULSE can only source/sink 2mA.
MAGNETOMETER
RC ELRS
GNSS
BUZZER
Pull-ups on I2C data lines: 2.7k for <10cm 10k for <5cm

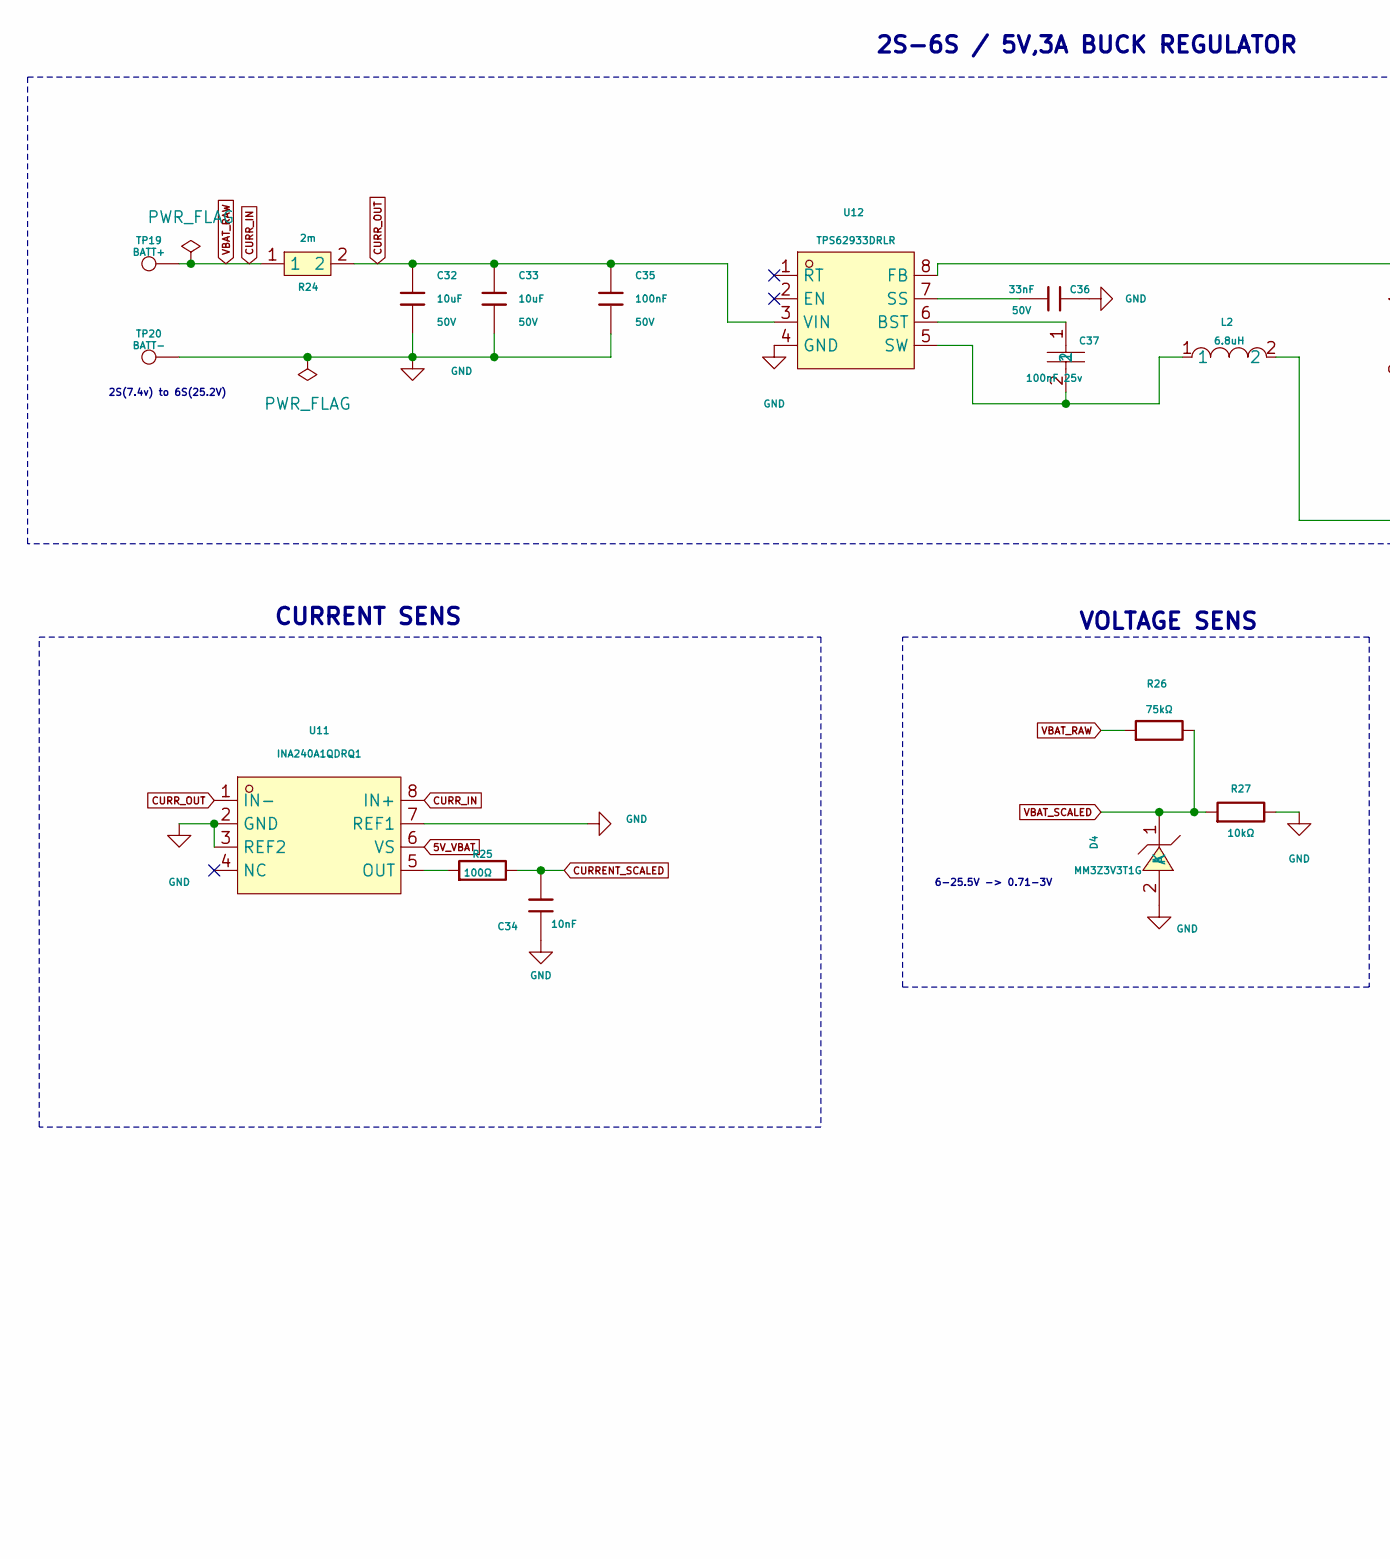
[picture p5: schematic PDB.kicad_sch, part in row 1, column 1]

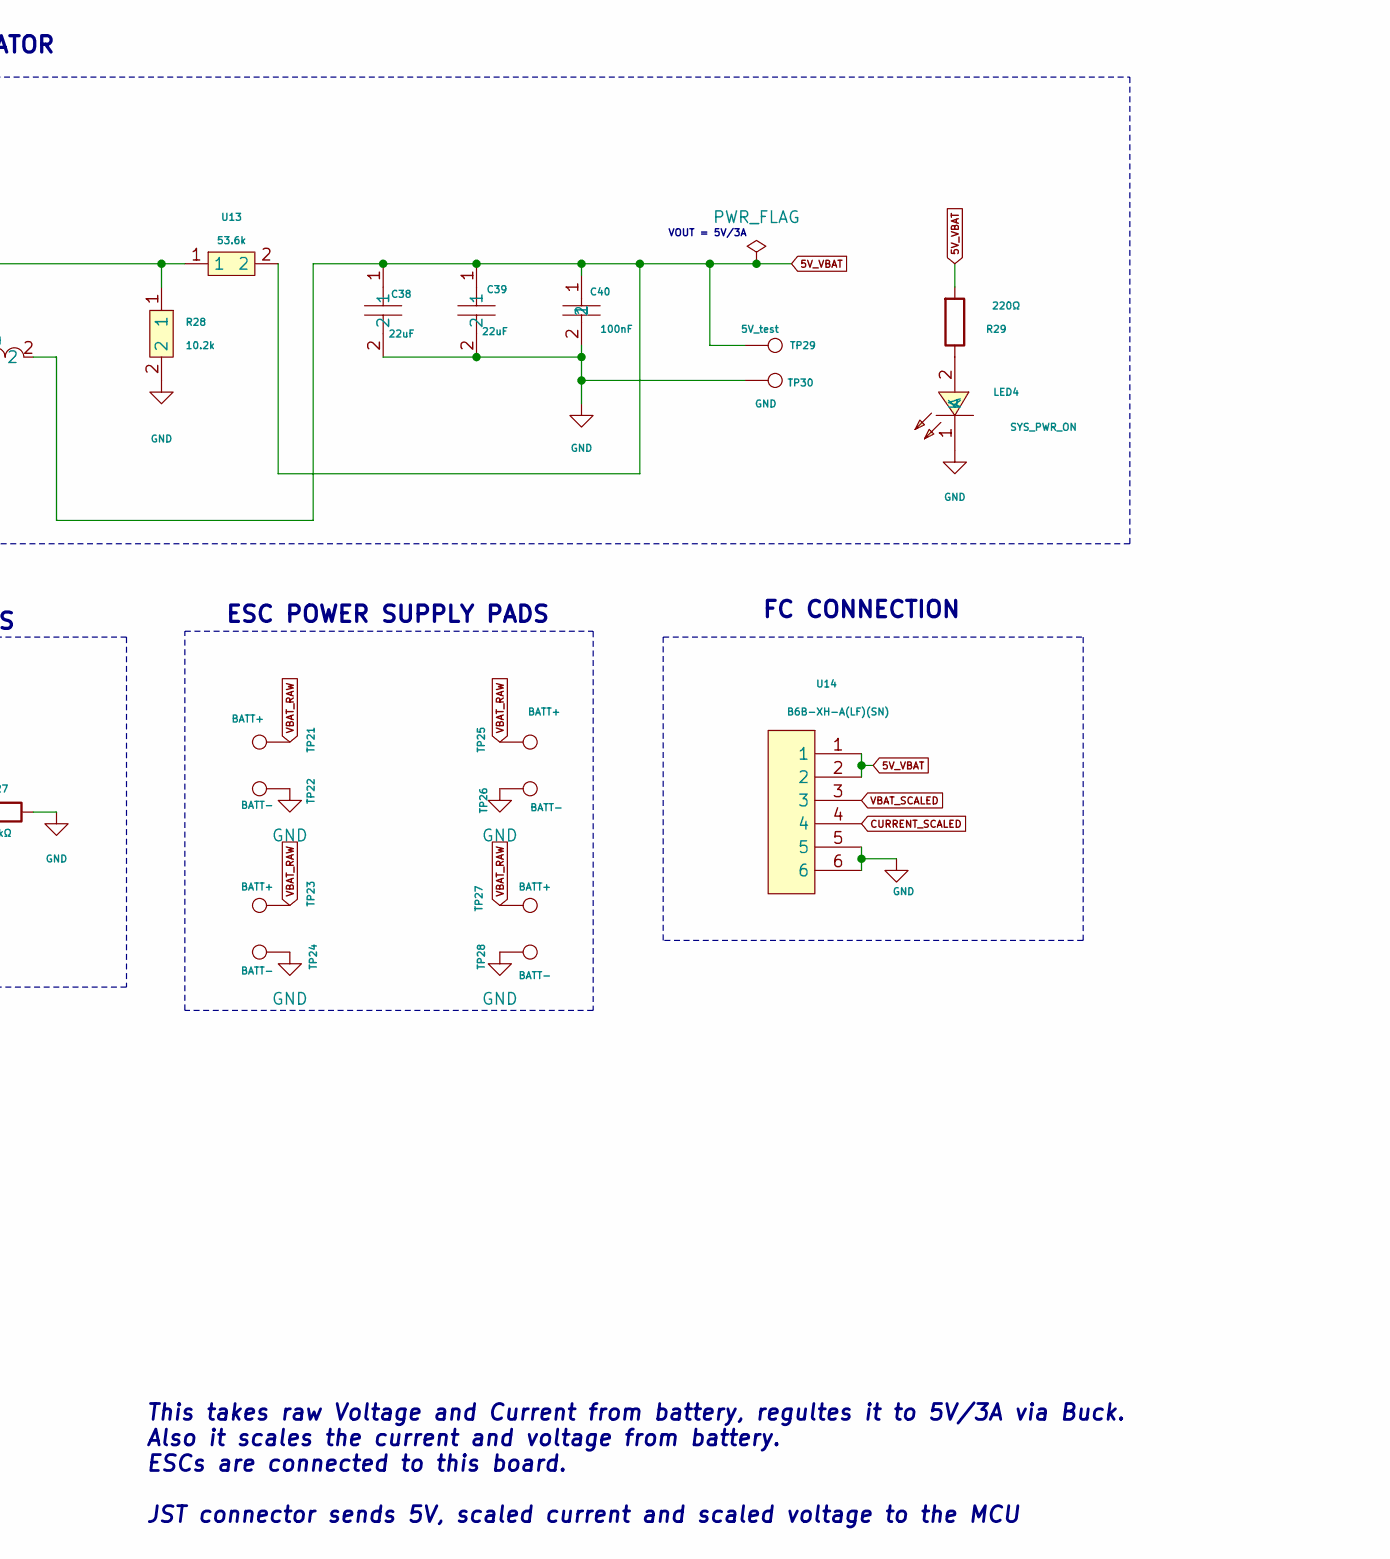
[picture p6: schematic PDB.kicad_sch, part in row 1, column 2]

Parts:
C32, C33: 10uF; C0805; Voltage Rated 50V; Tolerance ±10%; Part GRM21BR61H106KE43L; LCSC C440198
C34: 10nF; C0402; Voltage Rated 50V; Tolerance ±10%; Part CL05B103KB5NNNC; LCSC C15195
C35: 100nF; C0402; Voltage Rated 50V; Tolerance ±10%; Part CL05B104KB54PNC; LCSC C307331
C36: 33nF; C0603; Voltage Rated 50V; Tolerance ±10%; Part CL10B333KB8NNNC; LCSC C21117
C37: 100nF 25v; C0402; LCSC Part C100072
C38, C39: 22uF; C1206; LCSC Part C91604
C40: 100nF; C0402; LCSC Part C100072
D4: MM3Z3V3T1G; SOD-323_L1.8-W1.3-LS2.5-RD; LCSC Part C75073
L2: 6.8uH; IND-SMD_L7.1-W6.6; LCSC Part C5349706
LED4: SYS_PWR_ON; LED0603-RD; LCSC Part C2286
R24: 2m; RES-SMD_L6.4-W3.2-1; LCSC Part C2994640
R25: 100Ω; R0402; Overload Voltage (Max) 50V; Tolerance ±1%; Part 0402WGF1000TCE; LCSC C25076
R26: 75kΩ; R0402; Overload Voltage (Max) 50V; Tolerance ±1%; Part 0402WGF7502TCE; LCSC C25798
R27: 10kΩ; R0402; Overload Voltage (Max) 50V; Tolerance ±1%; Part 0402WGF1002TCE; LCSC C25744
R28: 10.2k; R0805; LCSC Part C2933282
R29: 220Ω; R0603; Overload Voltage (Max) 75V; Tolerance ±1%; Part 0603WAF2200T5E; LCSC C22962
TP19, TP21, TP23, TP25, TP27: BATT+; TestPoint_Pad_4.0x4.0mm
TP20, TP22, TP24, TP26, TP28: BATT-; TestPoint_Pad_4.0x4.0mm
TP29: 5V_test; TestPoint_Pad_D2.0mm
TP30: GND; TestPoint_Pad_4.0x4.0mm
U11: INA240A1QDRQ1; SOIC-8_L4.9-W3.9-P1.27-LS6.0-BL-2; LCSC Part C2057377
U12: TPS62933DRLR; SOT-583-8_L2.1-W1.2-P0.50-LS1.6-BR; LCSC Part C3200405
U13: 53.6k; R0603; LCSC Part C2930115
U14: B6B-XH-A(LF)(SN); CONN-TH_6P-P2.50_B6B-XH-A-LF-SN; LCSC Part C144397

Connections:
5V_VBAT: C38.1, C39.1, C40.1, L2.2, R29.1, TP29.1 (1_1), U11.6 (VS), U13.2, U14.1, U14.2; also elsewhere on the board
CURRENT_SCALED: C34.2, R25.2, U14.4; also elsewhere on the board
CURR_IN: R24.1, R26.1, TP19.1 (1_1), TP21.1 (1_1), TP23.1 (1_1), TP25.1 (1_1), TP27.1 (1_1), U11.8 (IN+)
CURR_OUT: C32.1, C33.1, C35.1, R24.2, U11.1 (IN-), U12.3 (VIN)
GND: C32.2, C33.2, C34.1, C35.2, C36.2, C38.2, C39.2, C40.2, D4.2 (A), LED4.1 (K), R27.2, R28.2, TP20.1 (1_1), TP22.1 (1_1), TP24.1 (1_1), TP26.1 (1_1), TP28.1 (1_1), TP30.1 (1_1), U11.2 (GND), U11.3 (REF2), U11.7 (REF1), U12.4 (GND), U14.5, U14.6; also elsewhere on the board
unnamed: LED4.2 (A), R29.2
unnamed: R25.1, U11.5 (OUT)
unnamed: C37.1, U12.6 (BST)
unnamed: R28.1, U12.8 (FB), U13.1
unnamed: C36.1, U12.7 (SS)
unnamed: C37.2, L2.1, U12.5 (SW)
VBAT_SCALED: D4.1 (K), R26.2, R27.1, U14.3; also elsewhere on the board

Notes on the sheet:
FC CONNECTION
VOLTAGE SENS
This takes raw Voltage and Current from battery, regultes it to 5V/3A via Buck. Also it scales the current and voltage from battery. ESCs are connected to this board. JST connector sends 5V, scaled current and scaled voltage to the MCU
ESC POWER SUPPLY PADS
2S-6S / 5V,3A BUCK REGULATOR
2S(7.4v) to 6S(25.2V)
VOUT = 5V/3A
6-25.5V -> 0.71-3V
CURRENT SENS

Board: 2 copper layers, 134 parts (0 on the bottom side), 76 nets, no tracks yet.

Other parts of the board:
C41, C42: 27uF; C0402
LED5: SYS_PWR_ON; LED0603-RD

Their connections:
GND: C41.1, C42.1, LED5.1 (K); also elsewhere on the board
HEXT_IN: C41.2; also elsewhere on the board
unnamed 56: C42.2; also elsewhere on the board

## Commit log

2026-04-09 init: ChariotFC Kicacd project
    [ChariotFC.kicad_pcb, ChariotFC.kicad_sch, PDB.kicad_sch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]
2026-04-11 GPS connections made
    [ChariotFC.kicad_sch, PDB.kicad_sch, Schematic-A.kicad_sch]
2026-04-11 corrected current sens and voltage sens to filter scaled current reading using RC filter and clamp voltage to 3.3 in case of over voltage respectiveley
    [PDB.kicad_sch]
2026-04-11 Cleaned up circuit
    [ChariotFC.kicad_sch, Schematic-A.kicad_sch]
2026-04-12 Added PWR flags, Changed MCU pins electrical characteristics to bidirectional, rectified some ERC errors
    [ChariotFC.csv, ChariotFC.kicad_sch, PDB.kicad_sch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]
2026-04-20 Put the orrect load capacitances fo the External Osc
    [ChariotFC.kicad_sch, Schematic-A.kicad_sch]
2026-05-09 Assigned proper footprints, Re-annotated, Connection modification for efficient PCB layout, First PCB update
    [ChariotFC.kicad_pcb, ChariotFC.kicad_sch, PDB.kicad_sch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]
2026-05-09 Update power distribution board specs and status
2026-05-12 Joind PDB Batt+ and Batt- pads to LiPo battery input net
    [ChariotFC.kicad_pcb, PDB.kicad_sch]
